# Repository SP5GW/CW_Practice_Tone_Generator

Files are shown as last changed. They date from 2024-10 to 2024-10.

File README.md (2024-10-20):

# CW_Practice_Tone_Generator

<p align="center">
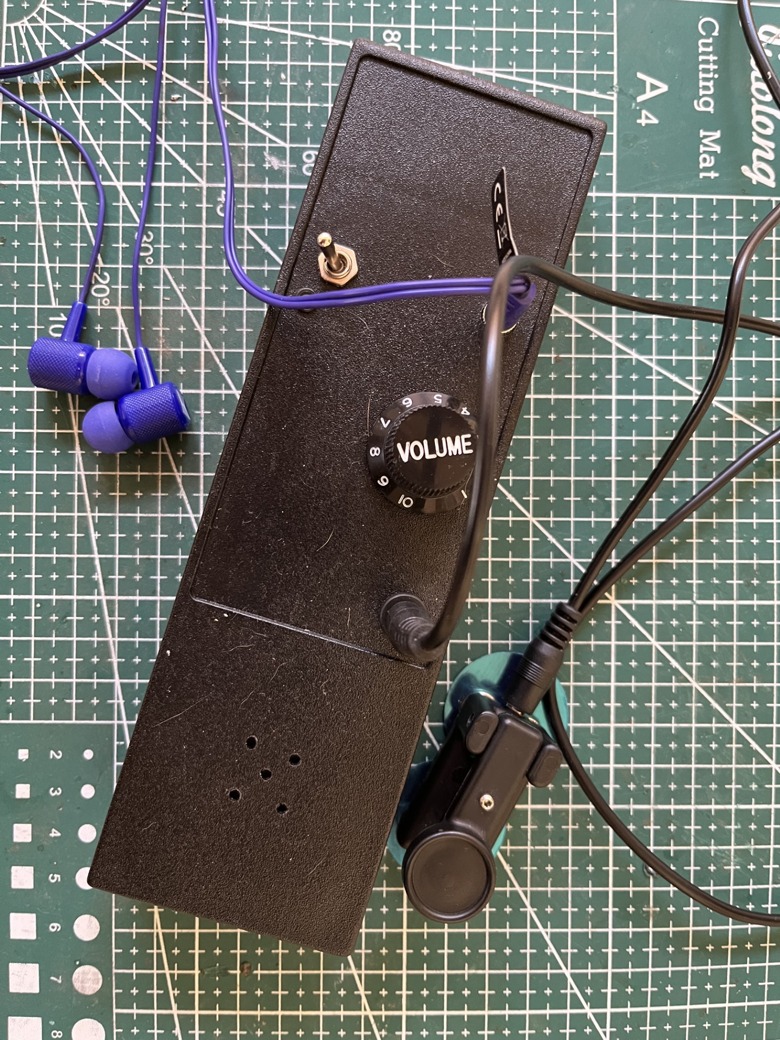
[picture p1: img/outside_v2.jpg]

</p> 

## Project overview

This project is a result of very real need to be able to practice when learning CW. There are many CW tone generator kits and reference designs on the internet, however I have not found one, which would allow connecting both speaker and head phones. Desings found on the internet also did not have volume control. 
When designing this project I was inspired by work described in [1] and [2].

It is not essential for this project to understand in detail how single Schmitt gate oscillator works, but if you are interested you will find all formulas and measurements in Appendix 1. 

Device schematics:

<p align="center">
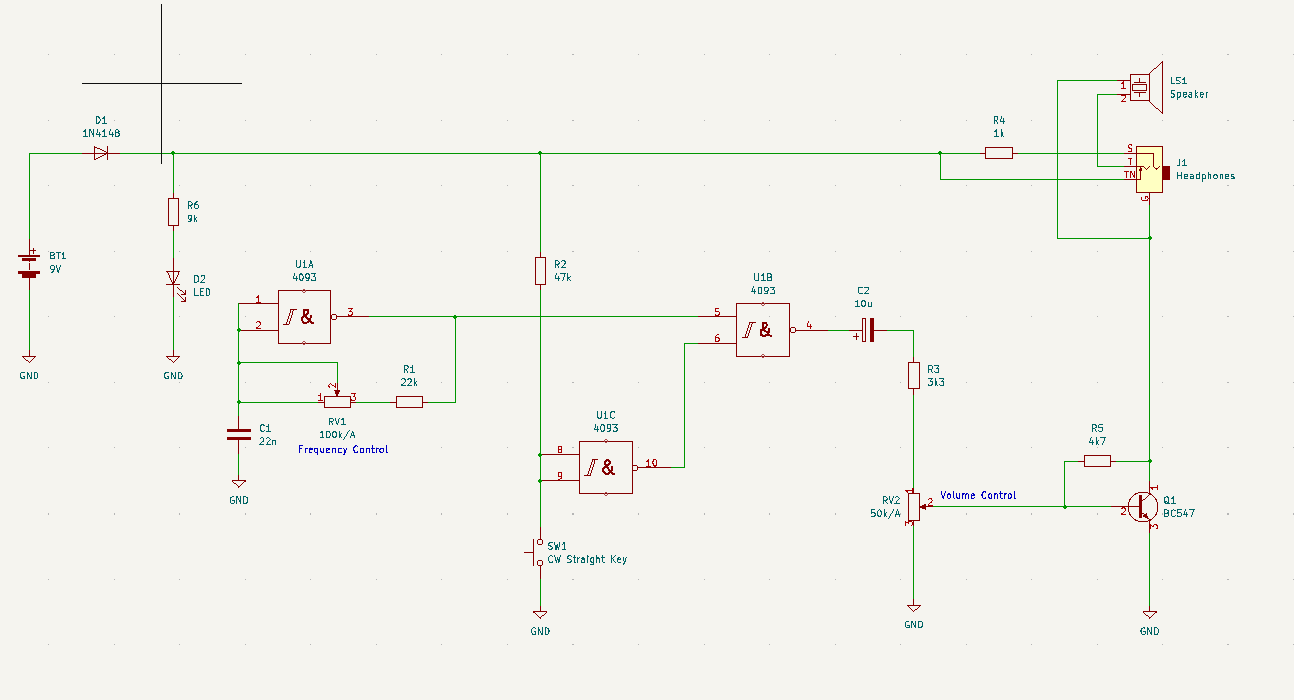
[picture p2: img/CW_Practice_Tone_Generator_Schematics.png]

</p>

Device internals:

<p align="center">
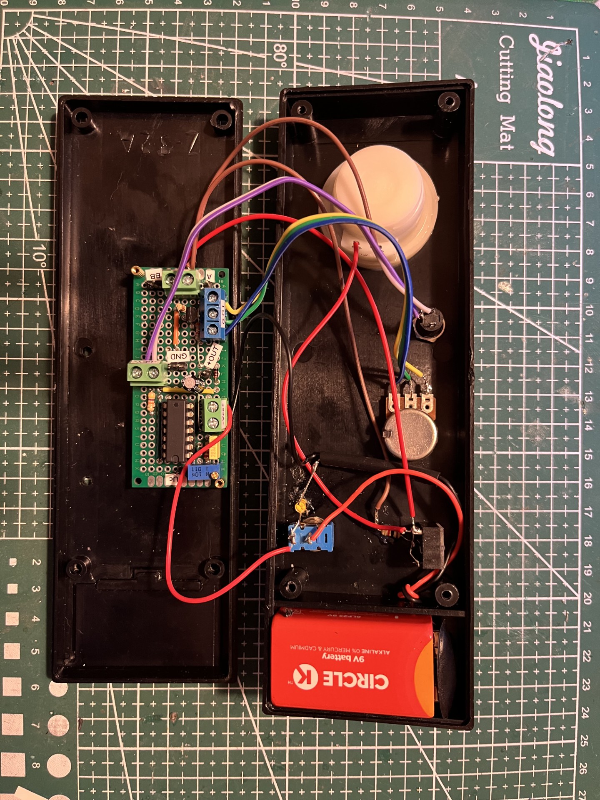
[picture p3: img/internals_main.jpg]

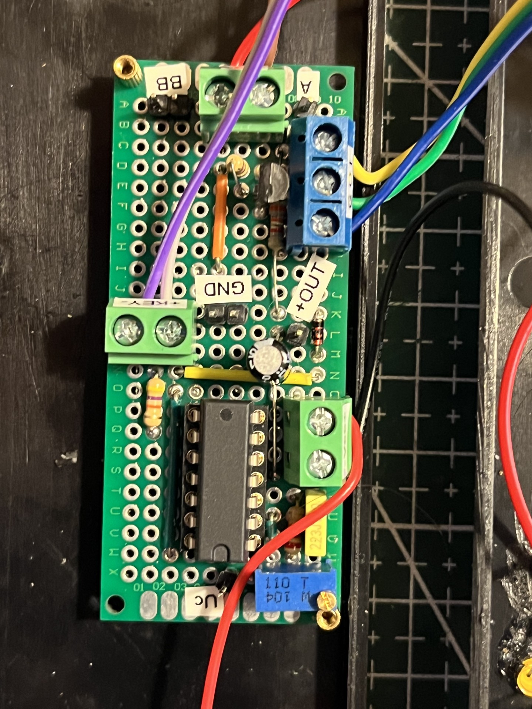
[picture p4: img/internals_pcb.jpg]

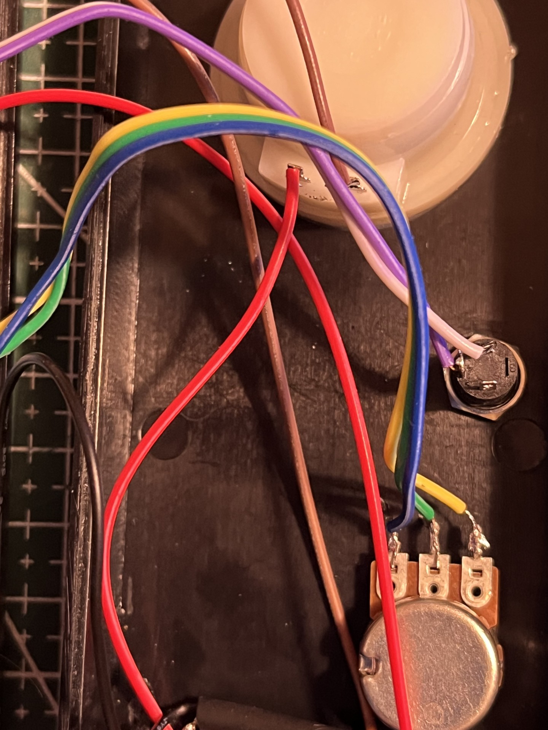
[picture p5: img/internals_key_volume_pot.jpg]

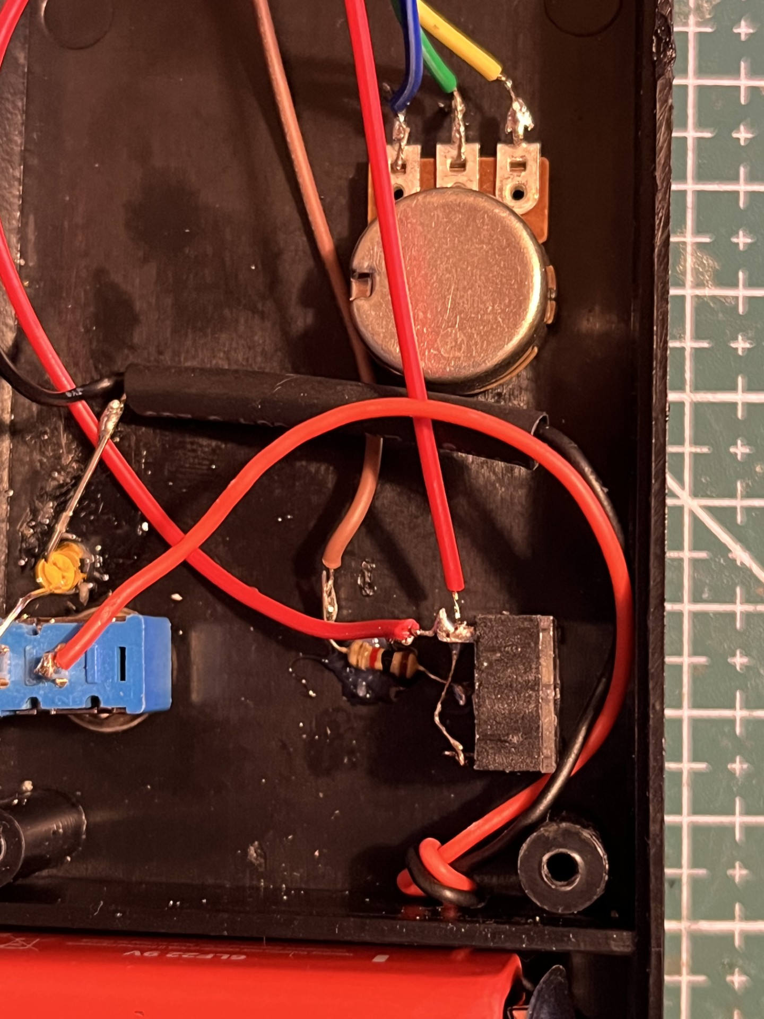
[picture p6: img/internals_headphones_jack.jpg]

</p>

## References

[1] [Generator Tonu by Radiohobby.pl](<https://radiohobby.pl/projekty/generator-tonu/>)

[2] [More Code Tone Generator Using the 4093 IC (ART159E)](<https://incbtech.com/index.php/articles/9-projects/642-morse-code-tone-generator-using-the-4093-ic-art159e>)

[3] [Exactly How Schmitt Trigger Oscillators Work by Eduardo Corpeno](<https://www.allaboutcircuits.com/technical-articles/exactly-how-schmitt-trigger-oscillators-work/>)

## Appendix 1 - Understanding Oscillator Design

<p align="center">
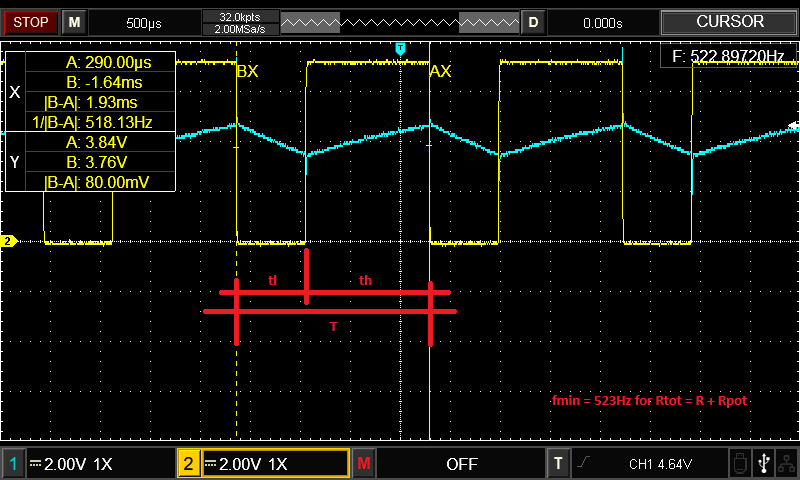
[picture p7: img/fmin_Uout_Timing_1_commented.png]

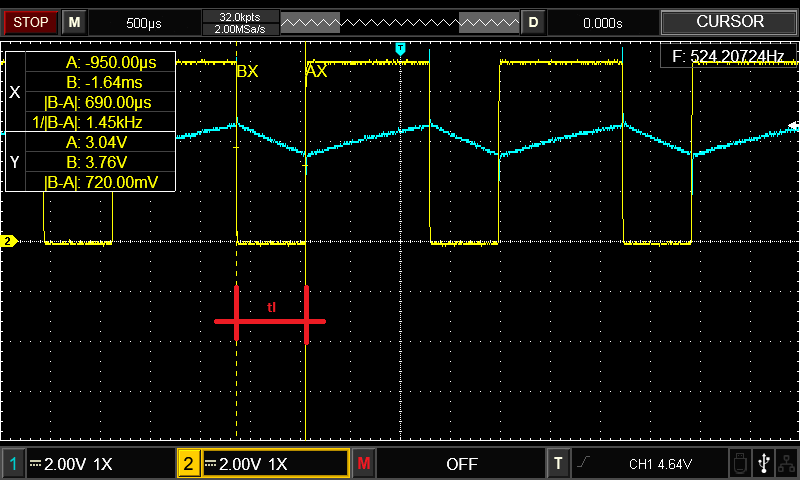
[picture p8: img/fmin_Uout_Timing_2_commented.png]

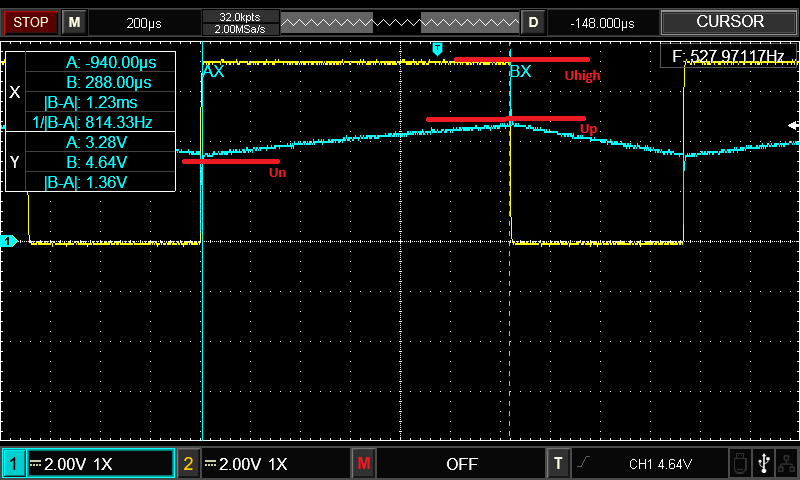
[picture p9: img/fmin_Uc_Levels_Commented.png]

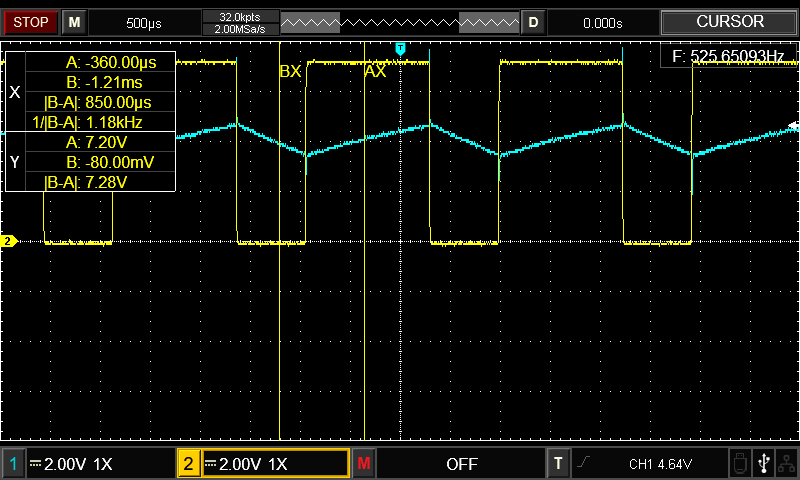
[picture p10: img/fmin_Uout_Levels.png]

</p>

Capacitor voltage during its charging phase can be expressed as:

$Uc(t)[V] = (Uhigh[V] - Un[V])(1-e^{\left(-\frac{t[sec]}{R[ohm]*C[F]}\right)}) + Un[V]$ *)

where:

$Uc(t)$ - Voltage across the capacitor at time t

$Uhigh$ - The supply voltage (or maximum voltage the capacitor will eventually charge to - in  our case theoretically)

$Un$ - The voltage level at which the Schmitt trigger output switches from low to high

$t$ - Time since charging began

$R$ - Resistance in the circuit (in ohms)

$C$ - Capacitance of the capacitor (in farads).

To calulate time it takes for capacitor voltage to reach Uc(t)=Up, we solve equation *) for t = th (i.e. th is a time instance when Uc(t) reaches Up)

$Up = (Uhigh - Un)(1-e^{\left(-\frac{th}{R*C}\right)}) + Un$

$\frac{Up - Un}{Uhigh - Un} = 1-e^{\left(-\frac{th}{R*C}\right)}$

$1 - \frac{Up - Un}{Uhigh - Un} = e^{\left(-\frac{th}{R*C}\right)}$

$\ln{(1 - \frac{Up - Un}{Uhigh - Un})} = \ln{e^{\left(-\frac{th}{R*C}\right)}}$

$-\frac{th}{R*C} = \ln{(1 - \frac{Up - Un}{Uhigh - Un})}$

$-th = R*C \ln{(1 - \frac{Up - Un}{Uhigh - Un})}$ 

$th = -R*C \ln{\frac{Uhigh - Un - Up + Un}{Uhigh - Un}}$

$th = -R*C \ln{\frac{Uhigh - Up}{Uhigh - Un}}$ 

from reciprocal rule $-\ln{x} = \ln{\frac{1}{x}}$, which in our case produces:

$th = R*C \ln{\frac{Uhigh - Un}{Uhigh - Up}}$

Similarly, the capacitor voltage during its discharging phase can be expressed as:

$Uc(t)[V] = Up*e^{(-\frac{t[sec]}{R[ohm]*C[F]})}$ **)

where:

$Uc(t)$ - Voltage across the capacitor at time t

$Uhigh$ - The supply voltage (or maximum voltage the capacitor will eventually charge to - in  our case theoretically)

$Up$ - The voltage level at which the Schmitt trigger output switches from high to low

$t$ - Time since charging began

$R$ - Resistance in the circuit (in ohms)

$C$ - Capacitance of the capacitor (in farads).

To calulate time it takes for capacitor voltage to reach $Uc(t)=Un$, we solve equation **) for $t = tl$ (i.e. $tl$ is a time instance when $Uc(t)$ drops from $Up$ to $Un$)

$Un = Up*e^{(-\frac{tl}{RC})}$

$\frac{Un}{Up} = e^{(-\frac{tl}{R*C})}$

$ln{\frac{Un}{Up}} = ln{e^{(- \frac{tl}{R*C})}}$

$-\frac{tl}{R*C} = ln{\frac{Un}{Up}}$

$tl = -R*C ln{\frac{Un}{Up}}$

from reciprocal rule: $-\ln{x} = \ln{\frac{1}{x}}$, which in our case produces:

$tl = R*C ln{\frac{Up}{Un}}$

The period of the oscillator's output signal can be expressed as:

$T = th + tl$

Using formulas for $th$ and $tl$ dervied earlier we can express $T$ as:

$T = R*C [\ln{\frac{Uhigh - Un}{Uhigh - Up}} + \ln{\frac{Up}{Un}}]$

from product rule: $\ln{x} + \ln{y} = ln{(x*y)}$, which in our case produce:

$T = R*C \ln{[(\frac{Uhigh - Un}{Uhigh - Up}) * (\frac{Up}{Un})]}$

consequently:

$f = \frac{1}{T} = \frac{1}{R*C \ln{[(\frac{Uhigh - Un}{Uhigh - Up}) * (\frac{Up}{Un})]}}$

Scope screenshots above are taken for $R = 21.9k + 101.7k = 123.6kohm$ (potentiometer set to its max. value), in this setting frequency is at its minimum, $fmin = 522Hz$, which coresponds to $T=1.93ms$ ($tl=0.69ms$, which means $th = T - th = 1.24ms).

Using above formulas and following voltage levels from scope screenshots above: $Un = 3.28V , Up = 4.64V , Uhigh = 7.2V, we arrive at following values (see [xls](<Oscillator_Calculator.xlsx>), Rmax column):

<p align="center">
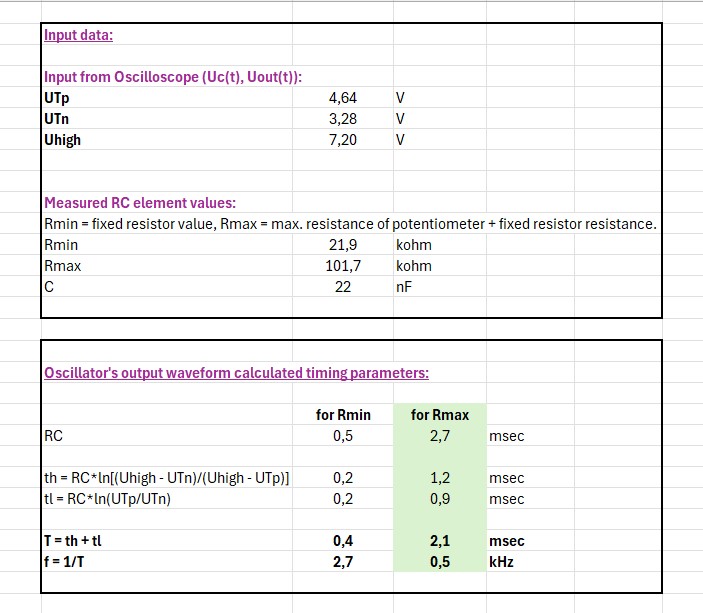
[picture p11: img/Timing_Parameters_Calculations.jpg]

</p>

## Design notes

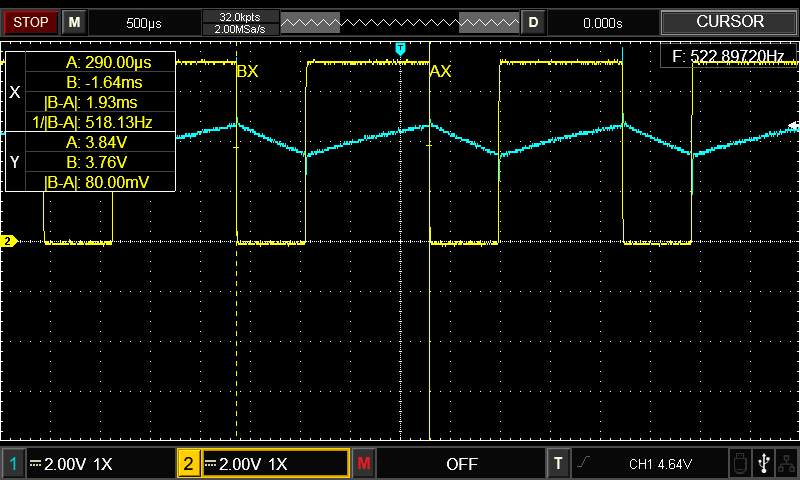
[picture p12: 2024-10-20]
img/fmin_Uout_Timing_1.png

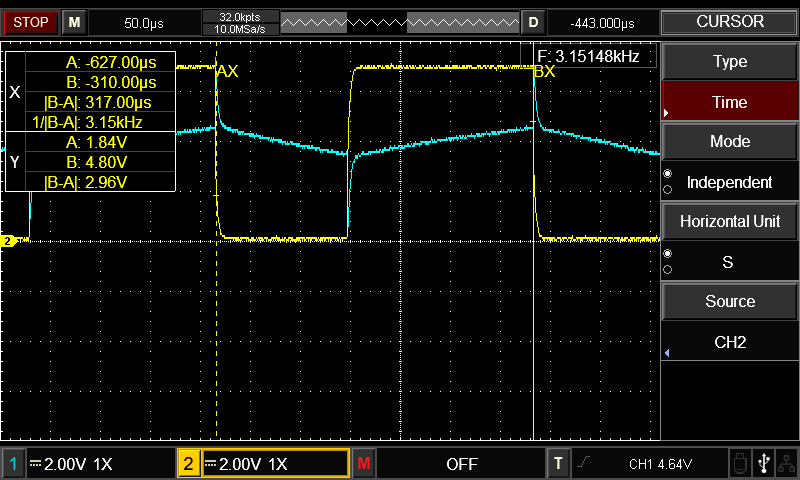
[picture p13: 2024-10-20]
img/fmax_Uout_Timing_1.png

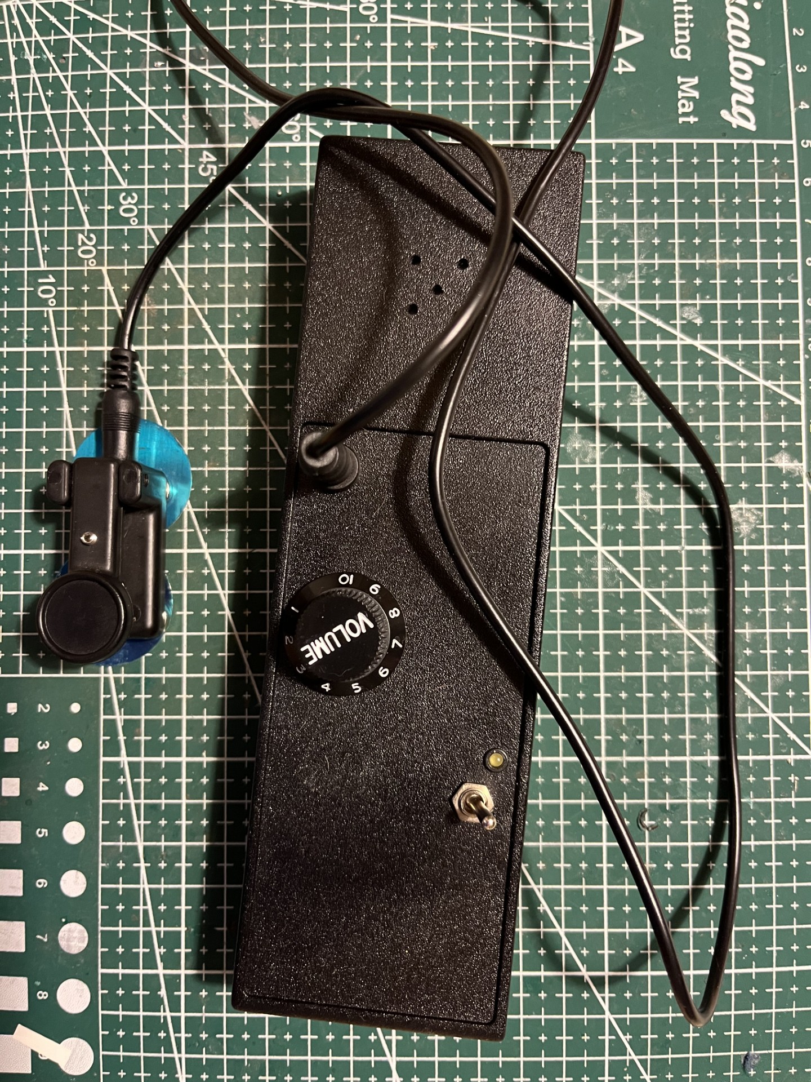
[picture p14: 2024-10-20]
img/outside_v1.jpg

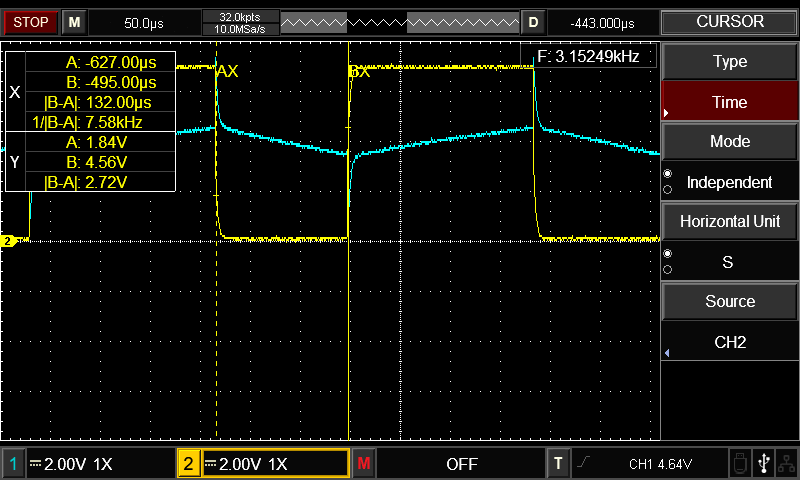
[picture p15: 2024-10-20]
img/fmax_Uout_Timing_2.png

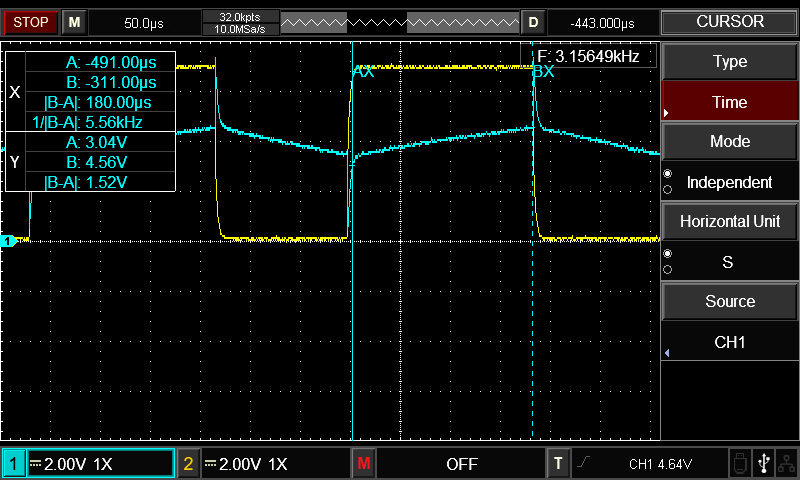
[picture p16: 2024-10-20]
img/fmax_Uc_Levels.png

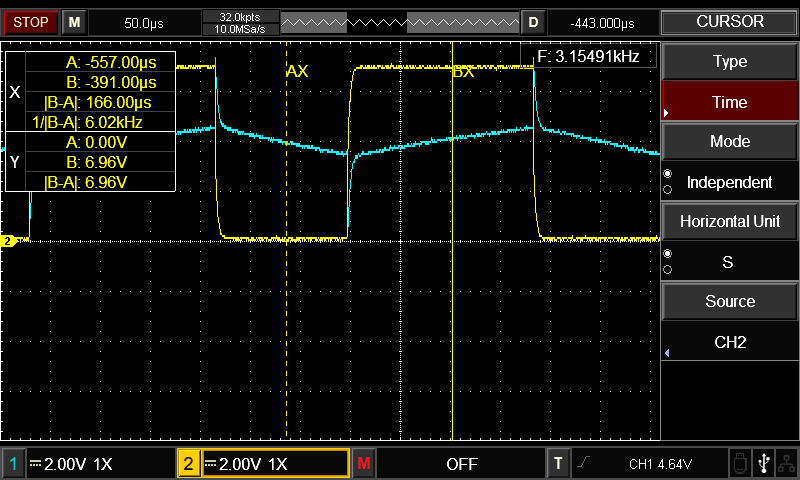
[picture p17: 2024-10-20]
img/fmax_Uout_Levels.png

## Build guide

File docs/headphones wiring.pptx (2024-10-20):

## Headphones socket wiring

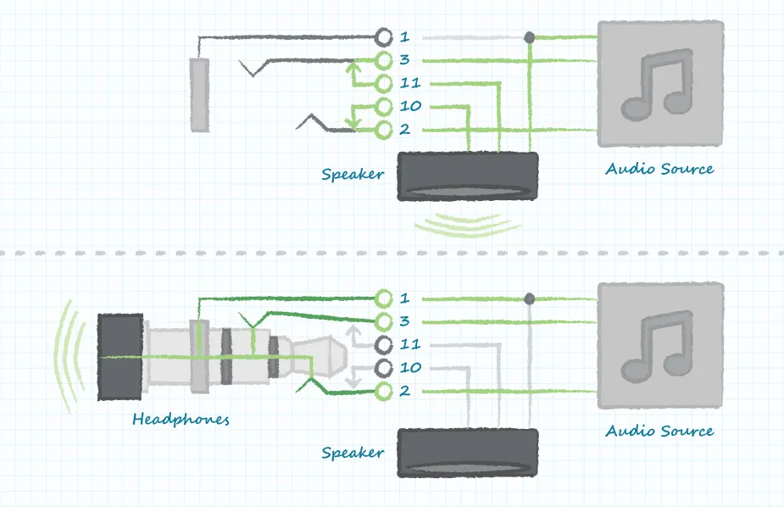
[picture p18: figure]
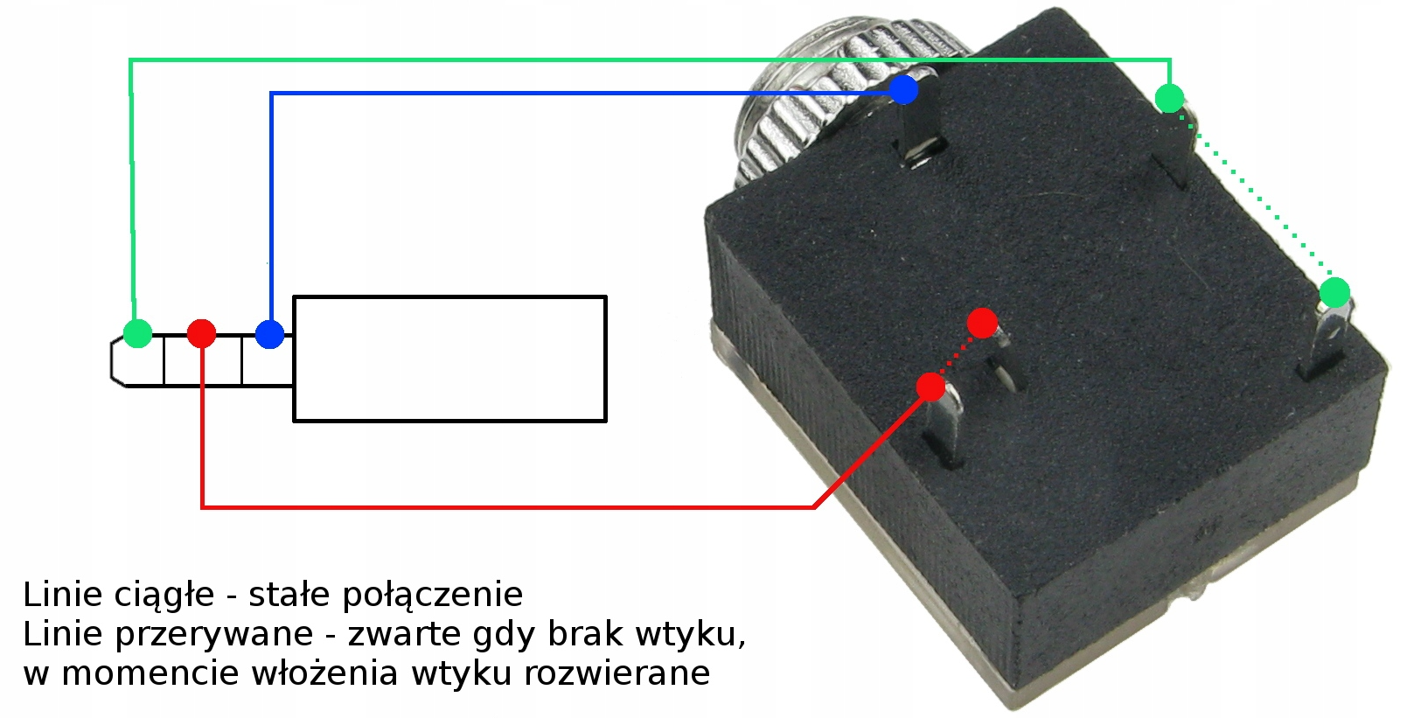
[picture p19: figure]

1

2

11

10

3

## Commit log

2024-10-20 schematics added
    [CW_Practice_Tone_Generator.kicad_sch, Oscillator_Calculator.xlsx]
2024-10-20 schematics resized
2024-10-20 scope printouts added
2024-10-20 scope prints resized
2024-10-20 charging formula completed
2024-10-20 charging timing ready
